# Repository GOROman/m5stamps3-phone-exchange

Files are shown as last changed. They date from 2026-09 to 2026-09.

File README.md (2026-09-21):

# M5StampS3 疑似電話交換機

M5Stack StampS3を使った、2回線対応の独立型アナログ疑似電話交換機です。

秋月電子の「PIC簡易疑似電話交換機キット」を現代化し、黒電話を含む2台の電話機で呼び出し・ベル鳴動・音声通話を行える装置を目指しています。公衆電話網（PSTN）には接続しません。

**設計やり直し中・発注禁止**

以前掲載した画像は手描きSVGであり、PCBやGerberからのレンダリングではありません。実データと一致しないため掲載を取り下げました。

## Rev.Bの設計資料

[Rev.B電気設計書](hardware/REV_B_DESIGN.md)に部品、端子接続、抵抗・コンデンサ定数、GPIO割当、呼出制御、評価手順を記載しました。

- M5StampS3は全端子を使う1.27mm接続版を採用する設計案です。
- Ag1171を2個使用し、5Vから回線給電・ベル生成・フック検出を行います。
- 音声はアナログ交差接続、呼出は20Hz・1秒鳴動／3秒休止です。
- 元の16Hzとの違いがあるため、黒電話の実機適合は未確認です。
- 電源保護・USB逆給電防止・独立ウォッチドッグは未確定です。
- **旧PCB、旧GPIO割当、既存ファームウェアはRev.B非対応です。**

呼出停止の[参照モデル](firmware/reference/ag1171_ring.h)と[単体テスト](tests/test_ag1171_ring.cpp)を追加しました。ホストで6つのテストブロックが合格しています。実機ファームウェアへの組込み、電気的検証、ERC/DRCは未実施です。

```sh
g++ -std=c++17 -Wall -Wextra -Werror -pedantic tests/test_ag1171_ring.cpp -o /tmp/test-ag1171-ring
/tmp/test-ag1171-ring
```

## Mini-pbx実例の反映

[参考元と採否](docs/mini-pbx-reference.md)を記録しました。受動音声回路への簡素化、Ag1171低背ソケット、DPモードの設計をRev.Bに反映しています。
[パルスダイヤル認識器](firmware/reference/pulse_dial.h)は独立した参照実装で、10/20ppsの全数字・バウンス・不正桁・切断・時刻周回をホストで検証済みです。
実GPIO・番号ルーティングへの組込み、実機試験は未実施です。参考元のコードや設計ファイルは転載していません。

```sh
g++ -std=c++17 -Wall -Wextra -Werror -pedantic tests/test_pulse_dial.cpp -o /tmp/test-pulse-dial
/tmp/test-pulse-dial
python3 scripts/check_audio_passive.py
```

## 目標仕様

- RJ11電話端子×2
- M5Stack StampS3による状態制御
- 回線ごとのループ電流／オフフック検出
- 一方の電話機からもう一方を呼び出し
- 応答後の双方向音声通話
- 切断検出後に待機状態へ復帰
- Wi-Fi設定とOTAアップデートは将来拡張（Rev.B初版の範囲外）
- JLCPCBで製造可能な2層基板

## 電源系統（Rev.B案）

安定化5V・2A以上を目標とし、StampS3と2個のSLICを給電します。従来の独立24V案は廃止しました。入力5Vでも電話端子には高電圧が発生します。電源保護回路とUSB同時接続への対策が未確定のため、現状は通電・発注用資料ではありません。

## リポジトリ構成

- `firmware/`：PlatformIO／Arduinoファームウェア
- `hardware/`：回路図、PCB、Gerber、製造資料
- `docs/`：アーキテクチャと安全要件

## 現在の状態（再点検結果）

- PCBファイルのネット定義・配線は0件です。電気回路として成立していません。
- StampS3のパッド番号・位置・径を公式2.54mm DIP資料に合わせて修正しました。外形は簡略図で、CAD読み込み・実装干渉・DRCの検証は未実施です。
- RJ11の実部品選定・寸法照合は未実施です。
- Rev.Bで主要回路の電気設計案を作成しました。CADへの回路実装と電源安全回路の設計は未完了です。
- PCB電源端子は未割り当てです。誤った12–24V表示は撤去済みです。旧PCBはRev.Bに使用できません。
- ファームウェアは未検証の骨格です。実回路、とくにリンガ駆動部へ接続しないでください。
- ERC（電気ルール検査）・DRC（設計ルール検査）・製造用Gerber生成は未実施です。`git diff --check`はこれらの代わりにはなりません。
- 旧画像は参考にしないでください。履歴確認のためファイルは残しています。

## やり直しの完了条件

1. Rev.Bの主要回路設計をレビューし、未確定の電源保護・独立停止回路を完成させる。
2. メーカー資料に基づく部品番号とフットプリントを確定する。
3. 回路図からネットリストを作成し、PCBへ反映する。
4. 配線・絶縁距離・電源保護・起動時のリンガ停止を検証する。
5. ERC／DRCの結果を保存し、未接続と違反を解消する。
6. Gerberとドリルを出力して別ビューアで照合し、その実データからREADME画像を生成する。
7. 試作前レビューを完了する。実機動作確認前に動作保証とは表記しない。

## ビルド

```sh
cd firmware
pio run
```

## 安全上の注意

リンガ回路ではSELV（安全特別低電圧）の範囲を超える電圧が発生します。電流制限、沿面距離・空間距離、保護されたテストポイント、絶縁ケースを設けてください。通電中の高電圧部には触れないでください。

## 参考資料

- [M5Stack StampS3公式ドキュメント](https://docs.m5stack.com/en/core/StampS3)
- [秋月電子 PIC簡易疑似電話交換機キット資料](https://akizukidenshi.com/img/contents/kairo/%E3%83%87%E3%83%BC%E3%82%BF/%E3%81%9D%E3%81%AE%E4%BB%96/L013_%E7%96%91%E4%BC%BC%E9%9B%BB%E8%A9%B1%E4%BA%A4%E6%8F%9B%E6%A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)

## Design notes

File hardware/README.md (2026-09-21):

# ハードウェア

設計CADはKiCadを使用し、JLCPCBでの2層FR-4基板製造を想定しています。必要に応じてEasyEDA Proへインポートします。

Rev.AはM5StampS3を交換可能な2.54mm DIP方式で搭載する制御キャリア基板です。公式M5Stackフットプリントのピン配置に合わせます。

## 設計ブロック

1. 5Vロジック電源と入力保護
2. StampS3キャリアとプログラミングアクセス
3. 電話機Aの回線給電とオフフック検出
4. 電話機Bの回線給電とオフフック検出
5. 音声経路と回線切り替え
6. 昇圧リンガ、Hブリッジ、電話機選択

## Rev.A PCB

`m5stamps3_phone_exchange.kicad_pcb`は、80mm×60mmの初期レイアウトです。StampS3、5Vロジック電源、RJ11×2、リンガ／音声拡張ヘッダを配置しています。

## 製造データ

- Gerber／NC Drill ZIP
- LCSC品番付きBOM CSV
- CPL（部品座標）CSV
- 実装図
- 回路図PDF

RJ11端子は`PRIVATE PHONE A`と`PRIVATE PHONE B`です。公衆電話網へ接続する端子は設けません。

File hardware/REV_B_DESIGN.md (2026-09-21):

# Rev.B 電気設計案：M5StampS3＋2回線SLIC

設計日：2026-09-21。設計レビュー用。製造リリースではありません。
この文書は旧Rev.Aの24V給電案・リレー制御案・GPIO割当を置き換えます。
既存PCBとファームウェアには未反映です。既存Gerber風画像は使用禁止です。

## 1. 実現する機能

屋内の独立したアナログ電話機2台を接続する。公衆回線、屋外配線、他の交換機の電話端子には接続しない。
一方をオフフックすると400Hz発信音、7秒後に他方を呼出、応答で双方向通話、片方の切断で残った側へ切断音を送る。
既定動作は7秒後の自動呼出。追加でDP（Dial Pulse：パルスダイヤル）モードを設計対象とする。
DPモードの内線番号はA=11、B=12。10/20ppsを目標とし、認識器の参照実装を追加した。番号ルーティングと実GPIOへの組込みは未実装。
同時オフフックは通話へ移行する。Wi-Fi、OTA、ナンバーディスプレイ、課金極性反転は初版の範囲外。

元キットは12V給電・PIC・音声アンプ＋逆接続トランスによる16Hz呼出である。
本設計は機能を再実装するもので、元基板のコピーではない。部品とファームウェアの互換性はない。

## 2. 採用回路

| ブロック | 部品／方式 | 選定理由 |
|---|---|---|
| 制御 U1 | M5StampS3、全28端子の1.27mm接続 | GPIO3等のストラップ端子を避けて制御線を確保 |
| 電話A U2／電話B U3 | Silvertel Ag1171 ×2 | 回線給電、呼出昇圧、ハイブリッド、フック検出を内蔵 |
| 制御電圧変換 U4 | SN74AHCT125、5V | 3.3V指令からSLICの5V制御入力へ |
| 検出電圧変換 U5 | SN74LVC2G17、3.3V | 5VのSHK信号をESP32へ直接入れない |
| 音声バイアス | 抵抗分圧＋コンデンサ | U6オペアンプを削除し受動回路へ簡素化 |
| 音声選択 U7 | CD74HCT4053、5V | 各電話への入力を相手音声／トーンから選択 |
| 入力電源 | 安定化5V、2A以上を設計目標 | SLIC2個とMCUの負荷・過渡電流に余裕を持たせる |

SLICは別途調達してソケットへ手実装する前提。JLCPCB実装サービスの在庫・価格・対応は未確認。
安価なディスクリート版より部品費が増える可能性がある。発注前に調達性と見積を確認する。

## 3. 電源と電気的境界

ネット名は `+5V_SYS`、`+3V3`、`GND`、`VMID` とする。
U1の5V端子には安定化5Vのみを供給する。U1の3V3出力はU5と小信号プルアップだけに使用し、SLICを給電しない。
U2/U3各13番へ5V、12番へGND。各モジュール直近に470µF/16V電解と100nF/25Vを並列配置する。
U4/U5/U7の電源直近にも各100nF。VMIDの分圧点に10µF/10Vと100nF/25Vを並列接続する。U6は欠番とする。

5V時のデータシート負荷条件では呼出最大480mA、通話最大400mA／モジュール。
一方を呼出・他方を通話給電する条件では880mA。MCU等に500mAの設計予算を置き、合計1.38Aから2A入力を目標にする。
これは全電話機・全過渡条件の保証ではない。入力電流制限は評価用電源から始める。

5V入力でもTIP/RINGは高電圧になる。SLICの内蔵DC/DCは安全絶縁を提供するものとして扱わない。
TIP/RINGからGNDへの接続、一般オシロのGNDクリップ接続は禁止。定格を満たす差動プローブを用いる。

**未確定の電源回路**：逆接・過電圧保護、突入制限、USBからの逆給電防止、独立ウォッチドッグによる給電停止。
これらは省略可能なオプションではなく、製造前に部品選定・回路図化・電源シーケンス検証が必要。
現段階では外部5VとStampS3のUSBを同時接続しない。書込みはSLICを外した状態で行う。

## 4. SLIC接続（U2/U3共通）

`P`をAまたはBとする。モジュール番号とESP32 GPIO番号を混同しない。

| Ag1171端子 | 信号 | 接続 |
|---|---|---|
| 1 | RING | `P_RING`、電話端子と保護ダイオードへ |
| 2 | TIP | `P_TIP`、電話端子と保護ダイオードへ |
| 3 | F/R | U4出力 `P_FR_5V` |
| 4 | RM | U4出力 `P_RM_5V` |
| 5 | SHK | U5入力 `P_SHK_5V` |
| 6,7,8,11 | NC | 全て未接続。テストパッドにも使わない |
| 9 | VIN | 10nF直列コンデンサ経由で音声選択出力 |
| 10 | VOUT | 100nF直列コンデンサ経由で受動音声分圧回路 |
| 12 | GNDPWR | GND |
| 13 | VPWR | +5V_SYS |
| 14 | PD | 評価案では開放。停止回路を追加する場合はLow／開放のみ |

PDをGPIOのPush-pull Highで駆動してはいけない。電源投入後100msはSHKを無視する設計とする。
電話端子はRJ11の中央2接点を使用するが、フットプリントの端子番号は部品選定後に機械図で確認する。
RJ11の他接点は未接続。J2/J3の型番未確定につき、既存の仮フットプリントを流用しない。

### 回線保護

メーカーFigure 4を基準とし、各回線に1N4004を4個配置する。以下は `アノード → カソード`。

- D_PA：GND → P_TIP
- D_PB：GND → P_RING
- D_PC：P_TIP → P_CLAMP_HI
- D_PD：P_RING → P_CLAMP_HI
- Z_P：P6KE82単方向。アノードをGND、カソードをP_CLAMP_HI。

Figure 4のZ_Pはカソード側がクランプ共通点である。TIP-RING間へTVSを1個置くだけの回路に置換しない。
各回線に専用クランプを配置し、帰路を短くする。CLI用20kΩ等のTIP-RING間抵抗は初版では付けない。
この保護は屋内用途のメーカー推奨最小構成を出発点にしたもので、雷・商用電源混触や規格適合を保証しない。

## 5. 制御線とレベル変換

| U1パッド | ESP32 GPIO | 信号 | 起動時 |
|---|---|---|---|
| 1 | 1 | A_RM_CMD | Low |
| 2 | 2 | A_FR_CMD | High |
| 4 | 4 | B_RM_CMD | Low |
| 5 | 5 | B_FR_CMD | High |
| 6 | 6 | A_SHK | 入力 |
| 7 | 7 | B_SHK | 入力 |
| 8 | 8 | A_AUDIO_SEL | Low |
| 9 | 9 | B_AUDIO_SEL | Low |
| 10 | 10 | TONE_PWM | Low |
| 12 | 11 | AUDIO_INHIBIT | High |
| 14 | 12 | WD_HEARTBEAT予約 | Low、未実装 |
| 13 | — | +5V_SYS | 5V入力 |
| 28 | — | +3V3 | U1の3.3V出力 |
| 11,18 | — | GND | 共通GND |

GPIO0/3/45/46は制御に使わない。公式1.27mmソケットまたはSMDの全端子版を用いる。
2.54mm DIP版では上記端子の一部が存在しないため不可。

U4：14=5V、7=GND、1/4/10/13（/OE）=GND。
2→3をA_RM、5→6をA_FR、9→8をB_RM、12→11をB_FRに割り当てる。
U4入力側RMに47kΩ対GND、FRに47kΩ対3V3を設ける。
5V SLICの制御High最小値3.5Vに対し、ESP32出力3.3Vの直接接続は不可。

U5：5=3V3、2=GND、1=A_SHK_5V、6=A_SHK、3=B_SHK_5V、4=B_SHK。
SHKはHigh=オフフック。旧ファームウェアのLow検出と逆なので流用禁止。
SHKには強いプルダウンやLEDを付けない。U5の入力負荷だけで受ける。

U7のINHIBITには47kΩ対3V3、選択入力には各47kΩ対GNDを設ける。
電源立上り中・MCU停止中の安全はこれだけでは保証できない。独立停止回路の設計が必要。

## 6. 音声回路と定数

音声をESP32へ取り込まず、SLICの4線音声を交差接続する。ADC/DAC、I2S CODEC、DSPは不要。
通話ゲインは初期値約−6dB／方向とし、実電話機の音量と発振余裕を測定して調整する。

### 中点電圧と音声入力

5V—10kΩ—`VMID`—10kΩ—GND。VMIDに10µFと100nFを並列接続する。約2.5V。
U6は削除する。旧U6のパッドや接続をPCBへ持ち込まない。

各回線VOUT—100nF—22kΩ—`P_AUDIO_BIAS`、P_AUDIO_BIAS—47kΩ—VMID。
VOUTのDCバイアスを切った後、スイッチの入力側で明示的に再バイアスする。
Mini-pbxのC1/C2短絡指示は同プロジェクト固有の訂正であり、この100nFを短絡する指示ではない。

### 音声選択

U7はCD74HCT4053を維持する。16=5V、7/8=GND、6=AUDIO_INHIBIT、11=A_AUDIO_SEL、10=B_AUDIO_SEL。
12=B_AUDIO_BIAS、13=TONE_BIAS、14=TO_A。
2=A_AUDIO_BIAS、1=TONE_BIAS、15=TO_B。
未使用C系統は9=GND、3/5=VMID、4=未接続。
TO_A／TO_Bから各10nFを経由して対応SLICのVINへ接続。
TO_A／TO_Bには各100kΩをVMIDへ接続し、ミュート時の浮きを防ぐ。

SEL=0は相手音声、SEL=1はトーン。INHIBIT=1では両回線とも音声遮断。
発信音時は発信側だけSEL=1、相手側はSEL=0。通話時は両側SEL=0。
切替はINHIBIT=1で行い、選択線とトーン出力を設定後に解除する。
同時に独立した2種類のトーンを出す機能はない。

Mini-pbxの4066による接続・切断を参考に、こちらではトーン選択と全体ミュートを1個で行う4053を残す。
5VのHC型をESP32から直接駆動する構成には変更しない。HCT型を使用する。

### 受動回路の利得計算

`scripts/check_audio_passive.py` で結合コンデンサ、抵抗分圧、スイッチ抵抗70Ω、VIN公称60kΩの負荷を含めて計算する。
VMIDは交流的に理想GND、VOUT抵抗は公称10Ωという近似。部品公差、電源雑音、スイッチ非線形、SLIC内部の周波数特性は含まない。

| 周波数 | 計算利得 |
|---|---|
| 300Hz | −8.27dB |
| 400Hz | −7.50dB |
| 1kHz | −6.49dB |
| 3.4kHz | −6.29dB |

これはVOUTから相手VINまでの計算値。実電話機での音量・発振・歪み・クロストーク測定が採用条件。
VMIDは共通なので、電源と回線間の結合が実測上問題ならバッファを再検討する。
SLICのVOUT負荷は高域でも概算43kΩ以上となり、公称の最小負荷10kΩより重くならない設計。

### 400Hzトーン

GPIO10—10kΩ—T1—10kΩ—T2。T1/T2から各22nFをGNDへ接続。
T2—1µF—100kΩ—TONE_BIAS、TONE_BIAS—22kΩ—VMID。
TONE_BIASをU7へ接続する。旧U6Dのトーンバッファも削除する。
コンデンサは無極性、定格16V以上。初期評価は400Hz/50%矩形波。
トーンはU7とVINからの負荷を受けるため、バッファ有りの旧レベル計算を流用しない。
目標は電話端子側100〜200mVrmsとし、実測で100kΩの注入抵抗を調整する。
2回線同時トーンではさらに負荷が変わる。初版では1回線へのトーン出力のみを使用する。

## 7. 呼出制御

初期値は20Hz、1秒鳴動＋3秒休止。16Hzはモジュール標準条件外のため初版では使用しない。
RMのHigh占有率は停止待ち時間を含めて33%を超えないよう管理する。無制限の連続鳴動は禁止。
一度に呼び出すのは片側のみ、全体の呼出タイムアウトは60秒。

1. 相手がオンフックであることを確認する。
2. RMをHigh、FRを25msごとに反転する。
3. SHKのHighを10ms連続確認したらFRをHigh固定にする。
4. その後20ms待ってRMをLowにする。休止・キャンセルでも同じ停止手順を使う。
5. 呼出停止が完了してから音声経路を有効にする。

制御周期は1msを目標とする。500msを超えるブロッキング処理を許さない。
10msはSHKのデバウンスであり、ダイヤルパルスを切断判定する時間ではない。
通常の切断はデバウンス後のLow継続500msで確定する。
DPモードの認識器は `firmware/reference/pulse_dial.h`。SHKの10msデバウンス、20〜100msのブレーク受付、250msのメーク継続で桁確定、10パルス=0とする。
これらは初期実装の受付窓で、規格適合の主張ではない。短いノイズ、11パルス以上、長すぎるフラッシュを数字として採用しない。
認識器は発信側のダイヤル受付中のみ使用し、鳴動中のSHKは別の応答検出で扱う。通話中はパルスを番号としてルーティングしない。
既定の自動呼出モードでは番号を解読しない。DPモードと自動呼出を混在させない。
発信者が切断した場合も相手の呼出を停止する。片側だけオフフックで残れば切断音を送り、再呼出しない。

`firmware/reference/ag1171_ring.h` は停止順序の独立参照モデル。実GPIOへは接続していない。
単体テストはロジックだけを検証し、電気的な安全や実時間精度は検証しない。
CPU停止時にはこのモデルも動かないので、独立ウォッチドッグの代わりにならない。

## 8. PCBへ進める条件

基板サイズ80×60mmは撤回する。Ag1171の長辺61mm、端子間の不均等ギャップ、RJ11寸法を実際に配置して決定する。
モジュールを単純な連続14ピンヘッダとして描かない。メーカー機械図とソケット実物を照合する。
Mini-pbxの短足モジュール実装報告を反映し、Ag1171は低背ソケットを前提とする。
候補は秋月103138の1×20低背ソケット。接触開始深さ、挿入長、抜け止め、基板との干渉は未検証であり、発注型番の確定とは扱わない。
KS0835Fは参考元で動作報告があるが、本設計では未採用・未検証。NC端子省略を含む実物寸法と電気仕様の確認なしに代替しない。
2層基板を目標とし、SLICとRJ11を近接、低電圧音声とDC/DC電流帰路を分離して配置する。
高電圧領域は基板端・取付穴・露出金属から離し、モジュール下への他信号配線を避ける。
配線幅、沿面／空間距離は材質・汚損度・過渡電圧・筐体条件を決めてから設定する。ここでは規格適合値を推測しない。

残るリリース阻害要因：

- 電源保護・USB逆流防止・ハードウェア停止回路の確定。
- RJ11、ソケット、保護素子の発注型番と機械寸法の確定。
- KiCad回路図作成、ERC、PCBへのネット反映、配線、DRC。
- ファームウェアの新回路対応、トーン生成、呼状態機械のテスト。
- 実機での呼出電圧、電源過渡、音声、発熱、CPU停止試験。
- 検証済みPCBからのGerber/ドリル出力と別ビューア照合。

## 9. 評価手順

1. SLICを抜いて5V/3V3/VMIDを確認。GPIOリセット時RM=Low、FR=High、音声遮断を確認。
2. SLICを1個だけ挿し、電源電流・SHK・無負荷電圧を定格内の計測器で確認。
3. 300Ω/2W以上の試験負荷を無通電で接続し、ループ電流とSHKを確認。抵抗は発熱する。
4. 実電話機1台で1回だけベル試験。応答時FR→RMの順序をロジアナで確認する。
5. 2台で音声試験。300/400/1000/3400Hzの利得、ハウリング、クリッピングを測定。
6. 起動、リセット、通信停止、片側切断、60秒タイムアウト、短絡を段階的に試験する。
7. 通常時だけでなく電源異常・CPU停止時にも高電圧が安全に止まることを確認してから製造承認する。

## 10. 一次資料

- [秋月電子・元キット資料](https://akizukidenshi.com/img/contents/kairo/%E3%83%87%E3%83%BC%E3%82%BF/%E3%81%9D%E3%81%AE%E4%BB%96/L013_%E7%96%91%E4%BC%BC%E9%9B%BB%E8%A9%B1%E4%BA%A4%E6%8F%9B%E6%A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)：動作と元回路。原本の著作権は原著作者に帰属。
- [Ag1171公式資料](https://silvertel.com/images/datasheets/Ag1171-datasheet-Low-cost-ringing-SLIC-with-single-supply.pdf)：v1.6、端子p5、呼出p6–7、保護p9、定格p12–14、寸法p15。
- [Ag117x評価基板マニュアル](https://silvertel.com/images/Eval-Board-User-Guides/EVALAg117x-Eval-Board-User-Manual.pdf)：2台接続のメーカー評価例。
- [M5Stack公式ハードウェア](https://github.com/m5stack/M5_Hardware)：StampS3のシンボルと1.27mmフットプリント。
- [SN74AHCT125](https://www.ti.com/lit/ds/symlink/sn74ahct125.pdf)
- [SN74LVC2G17](https://www.ti.com/lit/ds/symlink/sn74lvc2g17.pdf)
- [CD74HCT4053](https://www.ti.com/lit/ds/symlink/cd74hct4053.pdf)

## 11. Mini-pbxからの反映

[参考元と採否の記録](../docs/mini-pbx-reference.md)を参照。参考元のソース・回路図・Gerberは転載していない。

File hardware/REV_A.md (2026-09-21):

# Rev.A PCB

## 目的

M5StampS3を交換可能な状態で載せる、80 mm × 60 mmの2層キャリア基板です。
電話回線の高電圧リンガ回路はまだ検証中のため、Rev.Aでは拡張エリアとして予約しています。

## 端子

| Ref | 用途 |
|---|---|
| J1 | 5Vロジック電源入力 |
| J2 | PRIVATE PHONE A / RJ11 |
| J3 | PRIVATE PHONE B / RJ11 |
| J4 | GPIO制御・リンガ・音声回路拡張ヘッダ |
| U1 | M5StampS3用交換式ヘッダ領域 |

## 発注条件案

- 80 mm × 60 mm
- 2層 FR-4
- 1.6 mm厚
- 1 oz銅箔
- HASLまたは無鉛HASL
- 最小線幅／線間隔：0.2 mm以上
- スルーホール部品中心
- 初回：PCBのみ5枚

## 注意

StampS3は公式の2.54mm DIPフットプリントに合わせます。この実装方法で利用できるのは15ピンです。RJ11コネクタは実際に購入する部品の寸法確認後にフットプリントを最終確定します。

12〜24VをStampS3の5V端子へ直接入力してはいけません。電話回線用24V電源とロジック5V電源は分離して扱います。

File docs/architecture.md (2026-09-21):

# アーキテクチャ

## 電源ドメイン

1. `LOGIC_5V`：StampS3用の安定化済み5V電源
2. `LINE_24V`：電流制限した電話回線給電用電源
3. `RING_HV`：通常は停止している高電圧リンガ電源

初期試作ではロジックGNDと電話回線GNDを共通にします。リンガ回路が非絶縁・非接地構成になる場合は、制御信号をフォトカプラ等で絶縁します。

## 機能ブロック

```text
5V入力 ─────────────→ StampS3

24V入力 → 電流制限 → 電話機A/B → オフフック検出
       └→ リンガ昇圧／Hブリッジ → 電話機選択

電話機A音声 ←→ 保護・AC結合・音声経路 ←→ 電話機B音声
```

## 検証が必要な項目

- 日本の黒電話を鳴らすための電圧と周波数
- 昇圧方式とトランス／インダクタの選定
- ループ電流と給電抵抗の発熱
- 音声経路の挿入損失と側音
- リレーまたは半導体スイッチの選択
- DTMFとダイヤルパルスへの対応範囲

## ファームウェア工程

1. スイッチとLEDでオフフック入力を検証
2. 高電圧を使用せず状態機械を検証
3. リンガ許可信号のインターロックとウォッチドッグを追加
4. Wi-Fi設定画面を追加
5. ダイヤルパルスとDTMF検出を追加

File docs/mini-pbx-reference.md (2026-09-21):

# Mini-pbx実例からの設計反映

確認日：2026-09-21。参考：[takao-t/Mini-pbx](https://github.com/takao-t/Mini-pbx)。
確認資料はREADMEと `config.mcc/hal_pbx.c`。PDF回路図・Gerberの実データ照合は未実施。
READMEの確認時blob SHA：`0aace26dc9c61da13e27c5a956b6f4a98e59d479`。
著者の製作・動作報告と、こちらの実機検証は区別する。

## 採否

| 参考元の知見 | Rev.Bでの対応 |
|---|---|
| Ag1171×2、アナログスイッチで音声接続 | 既存SLIC方式を維持。オペアンプを除いた受動音声経路へ変更 |
| 4066で通話を開閉 | Rev.Bはトーン選択とミュートも必要なためHCT4053を維持 |
| 音声バイアス修正のためC1/C2短絡 | 修正の理由を反映。こちらはAC結合後の再バイアスを明示し、コンデンサを残す |
| Ag1171の短い端子と低背ソケット | 低背ソケットを実装要件に追加。接触深さの現物確認を残す |
| ダイヤルパルスとホットライン | 10/20ppsの認識器を独立実装。ルーティング・実GPIO接続は未実装 |
| PIC内部CLCによるデバウンス | ESP32向け参照ロジックで10msのデバウンスを実装 |
| KS0835Fの動作報告 | 代替候補として記録のみ。本設計の互換保証・採用にはしない |
| UART経由の逆給電報告 | USB／制御線を含む電源停止時の逆給電検証を製造前条件として維持 |

## 呼出処理をそのまま移さない理由

確認したHALでは呼出中の休止区間もRMがHighで、FRのみを固定している。
停止処理はRMをLowにした後FRをLowにする構成だった。
こちらはAg1171のメーカー資料を基準に、FR=High固定後20msを待ってRMをLowにする。
休止中はRM=Low。1秒鳴動に停止待ち20msを加えても4秒周期で25.5%となる設計を維持する。
この比較は実コードの読解結果で、参考元の実機故障を確認したものではない。

## 今回の検証と限界

- `tests/test_pulse_dial.cpp`：10/20ppsそれぞれ1〜0の全数字、バウンス、11パルス拒否、切断、長いフラッシュ、32bit時刻周回。
- `tests/test_ag1171_ring.cpp`：既存の呼出停止順序・周期テストを再実行。
- `scripts/check_audio_passive.py`：部品定数と負荷を含む受動音声経路の公称利得計算。
- 電話実機、音量、波形、温度、ソケットの嵌合、ERC/DRCは未検証。

DP認識の受付窓は設計初期値。黒電話の個体差、パルス比、遅延、フック操作による誤認識は実機で確認する。
参照ロジックは1ms程度の周期で動作させる前提。CPU停止・大きな周期遅延への安全機構ではない。
DPの内線番号A=11/B=12と既定の7秒自動呼出は設計仕様であり、現行アプリで選択できる機能ではない。

## 出典・利用条件

参考元READMEには改変時の継承元明示と商用利用禁止の条件がある。
本変更では参考元のソースコード・回路図・画像・Gerberをリポジトリへコピーしていない。
パルス認識器、テスト、小信号計算スクリプトは本プロジェクトで新規に記述したもの。
参考元の成果物を将来取り込む場合は、既存MITライセンスへ無条件に含めず、その利用条件を個別に確認する。

一次資料：

- [Mini-pbx README](https://github.com/takao-t/Mini-pbx/blob/main/README.md)
- [Mini-pbx HAL](https://github.com/takao-t/Mini-pbx/blob/main/config.mcc/hal_pbx.c)
- [Ag1171データシート](https://silvertel.com/images/datasheets/Ag1171-datasheet-Low-cost-ringing-SLIC-with-single-supply.pdf)
- [CD74HCT4053データシート](https://www.ti.com/lit/ds/symlink/cd74hct4053.pdf)
- [CD74HCT4066データシート](https://www.ti.com/lit/ds/symlink/cd74hct4066.pdf)
- [低背ソケット候補：秋月103138](https://akizukidenshi.com/catalog/g/g103138/)

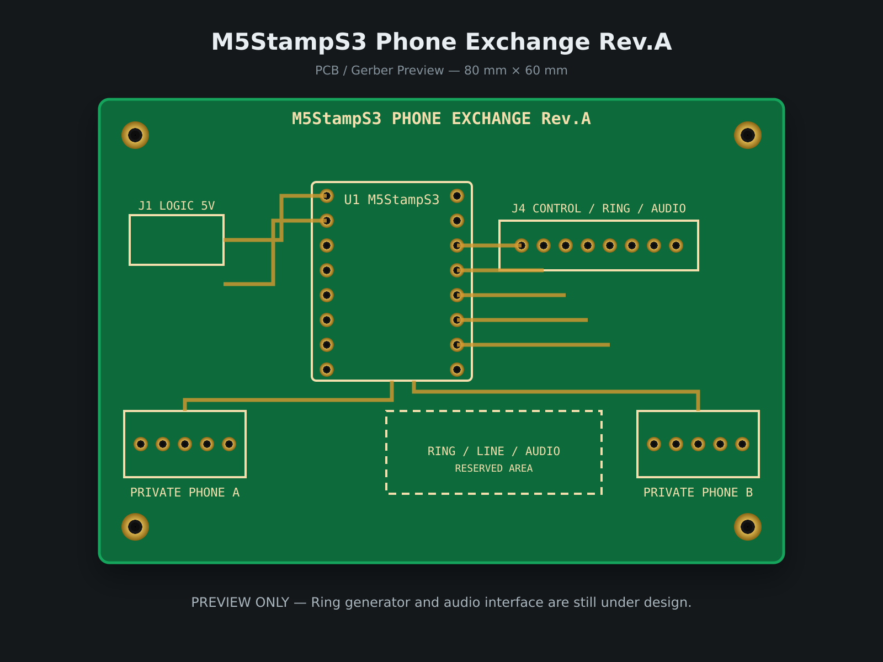
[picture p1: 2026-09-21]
docs/images/pcb-rev-a-gerber-preview.png

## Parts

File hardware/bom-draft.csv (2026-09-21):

Designator | Function | Initial choice | Status
U1 | Controller | M5Stack StampS3 S007 | selected
J1 | DC input | 5.5x2.1mm barrel or pluggable terminal | pending
J2;J3 | Private phone ports | RJ11 6P2C | pending footprint
U2 | 5V buck regulator | 24V-capable synchronous buck | pending
U3;U4 | Hook detector | Dual comparator or optocoupler | pending
Q1..Qn | Line/ring switching | Voltage-rated MOSFETs | pending
F1 | Input protection | Resettable fuse | pending
D1 | Input TVS | Supply-rated TVS | pending
F2 | Ring protection | Fusible/current limiting element | pending

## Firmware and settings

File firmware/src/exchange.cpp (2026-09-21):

#include "exchange.h"

#include "board_pins.h"

namespace {
constexpr uint32_t kSeizeDelayMs = 300;
constexpr uint32_t kReleaseGuardMs = 500;
constexpr uint32_t kRingCadenceOnMs = 1000;
constexpr uint32_t kRingCadencePeriodMs = 3000;
}  // namespace

void Exchange::begin() {
  pinMode(board::kOffHookA, INPUT_PULLUP);
  pinMode(board::kOffHookB, INPUT_PULLUP);
  pinMode(board::kLineRelayA, OUTPUT);
  pinMode(board::kLineRelayB, OUTPUT);
  pinMode(board::kRingEnable, OUTPUT);
  pinMode(board::kRingPolarity, OUTPUT);
  transition(ExchangeState::Idle, millis());
}

bool Exchange::offHookA() const { return digitalRead(board::kOffHookA) == LOW; }
bool Exchange::offHookB() const { return digitalRead(board::kOffHookB) == LOW; }

void Exchange::transition(ExchangeState next, uint32_t nowMs) {
  state_ = next;
  enteredAtMs_ = nowMs;
  Serial.printf("state=%u\n", static_cast<unsigned>(state_));
}

void Exchange::update(uint32_t nowMs) {
  const bool a = offHookA();
  const bool b = offHookB();
  const uint32_t elapsed = nowMs - enteredAtMs_;

  switch (state_) {
    case ExchangeState::Idle:
      if (a && !b) transition(ExchangeState::SeizeA, nowMs);
      else if (b && !a) transition(ExchangeState::SeizeB, nowMs);
      break;
    case ExchangeState::SeizeA:
      if (!a) transition(ExchangeState::ReleaseGuard, nowMs);
      else if (elapsed >= kSeizeDelayMs) transition(ExchangeState::RingB, nowMs);
      break;
    case ExchangeState::SeizeB:
      if (!b) transition(ExchangeState::ReleaseGuard, nowMs);
      else if (elapsed >= kSeizeDelayMs) transition(ExchangeState::RingA, nowMs);
      break;
    case ExchangeState::RingA:
    case ExchangeState::RingB:
      if (!a && !b) transition(ExchangeState::ReleaseGuard, nowMs);
      else if (a && b) transition(ExchangeState::Connected, nowMs);
      break;
    case ExchangeState::Connected:
      if (!a || !b) transition(ExchangeState::ReleaseGuard, nowMs);
      break;
    case ExchangeState::ReleaseGuard:
      if (elapsed >= kReleaseGuardMs && !a && !b)
        transition(ExchangeState::Idle, nowMs);
      break;
    case ExchangeState::Fault:
      break;
  }

  applyOutputs(nowMs);
}

void Exchange::applyOutputs(uint32_t nowMs) {
  const bool connected = state_ == ExchangeState::Connected;
  const bool ringing = state_ == ExchangeState::RingA ||
                       state_ == ExchangeState::RingB;
  const uint32_t phase = (nowMs - enteredAtMs_) % kRingCadencePeriodMs;
  const bool cadenceOn = ringing && phase < kRingCadenceOnMs;

  digitalWrite(board::kLineRelayA, connected ? HIGH : LOW);
  digitalWrite(board::kLineRelayB, connected ? HIGH : LOW);
  digitalWrite(board::kRingEnable, cadenceOn ? HIGH : LOW);

  // Slow polarity reversal placeholder. The final hardware driver will create
  // a current-limited 16-20 Hz ringing waveform.
  digitalWrite(board::kRingPolarity, ((nowMs / 25U) & 1U) ? HIGH : LOW);
}

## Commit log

2026-09-21 Add firmware and hardware design scaffold
    [bom-draft.csv]
2026-09-21 日本語READMEに更新
2026-09-21 Add Rev.A PCB status to Japanese README
2026-09-21 Document Rev.A carrier PCB
2026-09-21 Add Rev.A PCB manufacturing notes
2026-09-21 Add initial Rev.A carrier PCB layout
    [m5stamps3_phone_exchange.kicad_pcb]
2026-09-21 日本語ドキュメントと基板プレビューを追加
2026-09-21 誤った基板画像と進捗表示を撤回し、設計再点検結果を明記
2026-09-21 公式2.54mm DIP資料に基づきStampS3パッドを修正・未配線の製造禁止表示
    [m5stamps3_phone_exchange.kicad_pcb]
2026-09-21 StampS3パッドの修正範囲と未検証項目を明確化
2026-09-21 ネット・配線・回路図がない基板を不合格にする最低限の検査を追加
2026-09-21 Rev.B: SLIC方式の電気設計と呼出停止参照モデルを追加
2026-09-21 READMEをRev.B設計と検証済み・未完了範囲に更新
2026-09-21 Mini-pbx実例を参考に独立したDP認識・音声計算・設計記録を追加
2026-09-21 Rev.Bを受動音声回路・低背ソケット・DP認識仕様へ更新
